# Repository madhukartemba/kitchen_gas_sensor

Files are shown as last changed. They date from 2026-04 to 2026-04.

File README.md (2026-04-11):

# kitchen_gas_sensor

This is a kitchen gas sensor using ESPHome. It detects gas leaks using an MQ-6 sensor and triggers an active buzzer alarm.

---

## 🔧 Hardware
- ESP32-C3
- MQ-6 Gas Sensor (analog output)
- Active buzzer
- 1x NeoPixel (status LED)
- Push button (reset)

---

## 🚀 Setup & Build

ESPHome version used: 2026.1.5
Python version used: 3.12.10

### ✅ Run
```bash
python -m esphome -s device_id 0 run gas_sensor.yaml
```

### ✅ Repair (Windows)
```bash
Remove-Item -Recurse -Force $env:USERPROFILE\.platformio -ErrorAction SilentlyContinue
Remove-Item -Recurse -Force .\.esphome -ErrorAction SilentlyContinue
```

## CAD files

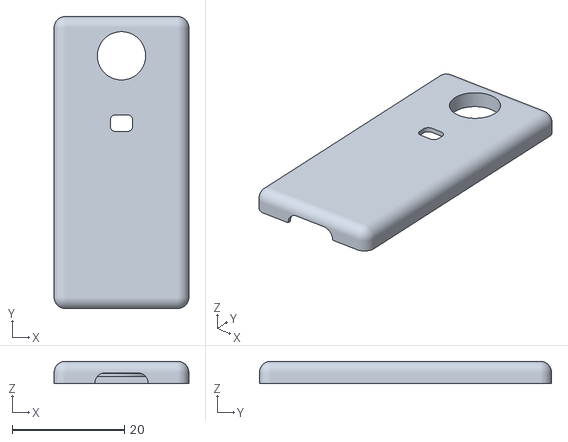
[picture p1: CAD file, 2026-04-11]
3D_Print/V2/Top.stl
24.0 x 52.0 x 4.00

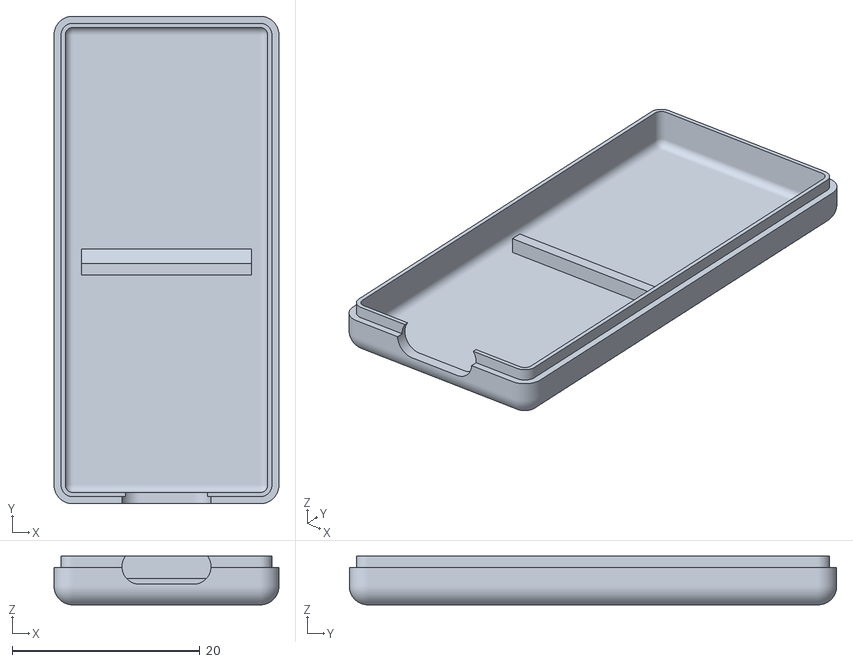
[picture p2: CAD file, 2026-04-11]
3D_Print/V2/Bottom.stl
24.0 x 52.0 x 5.20

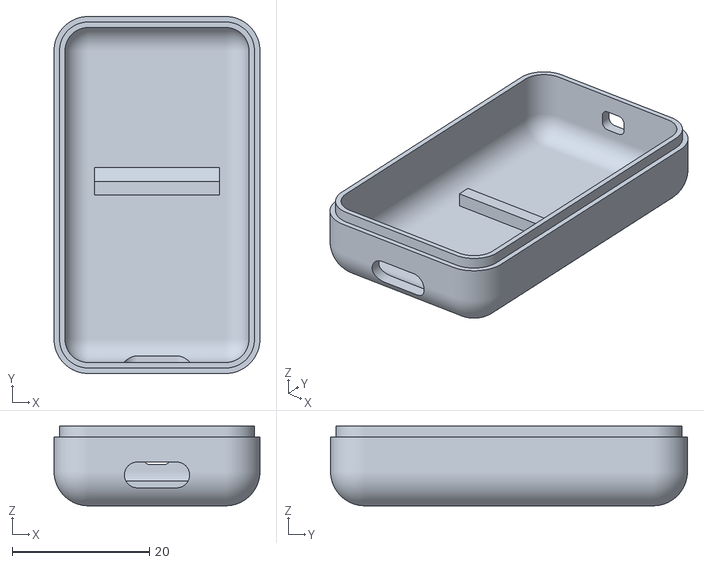
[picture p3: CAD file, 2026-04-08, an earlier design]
3D_Print/V1/Bottom.stl
30.0 x 52.0 x 11.6

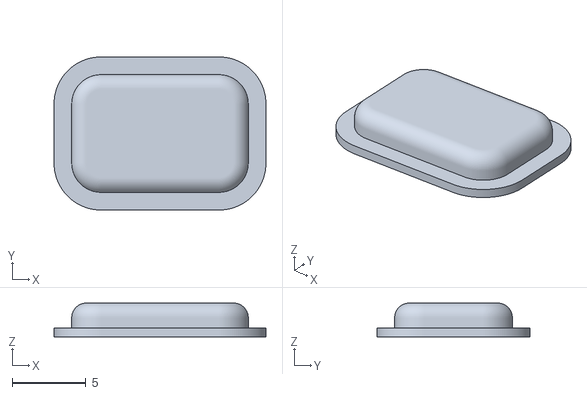
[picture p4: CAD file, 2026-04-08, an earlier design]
3D_Print/V1/LedCover.stl
14.4 x 10.4 x 2.30

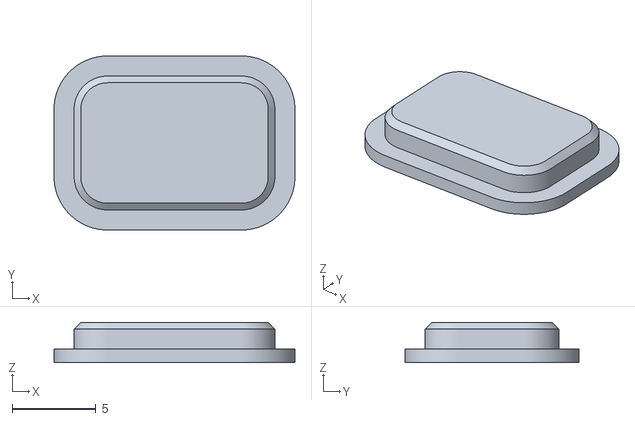
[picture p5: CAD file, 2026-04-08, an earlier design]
3D_Print/V1/Button.stl
14.4 x 10.4 x 2.40

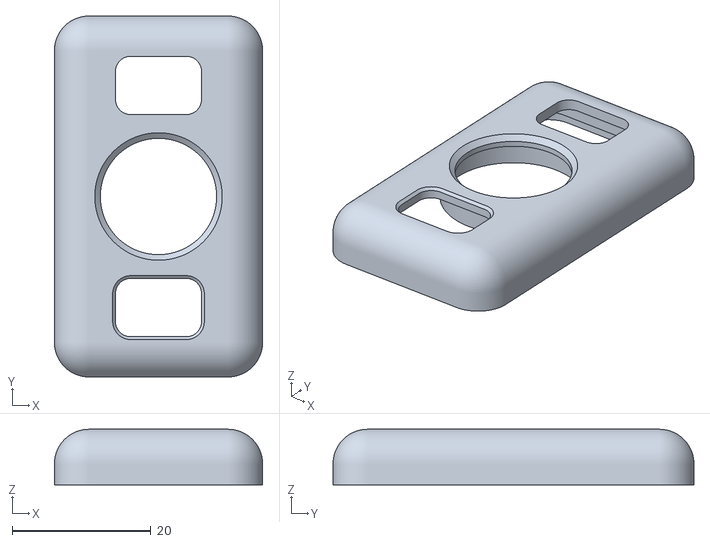
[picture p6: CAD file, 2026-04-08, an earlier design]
3D_Print/V1/Top.stl
30.0 x 52.0 x 8.00

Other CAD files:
3D_Print/V1/KitchenGasSensor.f3d
3D_Print/V2/GasSensorV2.f3d

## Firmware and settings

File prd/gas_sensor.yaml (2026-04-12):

substitutions:
  device_id: "0"

esphome:
  name: kitchen-gas-alarm-${device_id}
  friendly_name: Kitchen Gas Alarm ${device_id}
  # Include your custom C++ header
  includes:
    - SensorProcessor.h
  on_boot:
  # --- HARDWARE TEST ---
    - priority: 600
      then:
        - switch.turn_on: buzzer
        - light.turn_on:
            id: status_led
            red: 100%
            green: 100%
            blue: 100%
            brightness: 50%
            effect: "None"
        - delay: 1s
        - switch.turn_off: buzzer
        - light.turn_off: status_led
        - lambda: 'id(self_test_done) = true;'
    - priority: -10
      then:
        - lambda: |-
            get_processor()->setAbsoluteThreshold(id(gas_threshold).state);
            get_processor()->setRelativeThreshold(id(gas_rel_threshold).state);
            get_processor()->setNumberOfReadings(static_cast<int>(id(gas_reading_count).state));
            get_processor()->setWarmupTimeMs(static_cast<unsigned long>(id(gas_warmup_seconds).state * 1000.0f));
            get_processor()->setCooldownTimeMs(static_cast<unsigned long>(id(gas_cooldown_seconds).state * 1000.0f));
            get_processor()->setFaultVolts(id(gas_fault_trip_volts).state);
            get_processor()->setFaultClearVolts(id(gas_fault_clear_volts).state);

esp32:
  board: esp32-c3-devkitm-1
  framework:
    type: esp-idf

wifi:
  ssid: !secret wifi_ssid
  password: !secret wifi_password

logger:

api:

ota:
  - platform: esphome

# 🚩 Track if the startup test has finished
globals:
  - id: self_test_done
    type: bool
    initial_value: 'false'

# 1. Analog Gas Sensor - Exposed to HA
sensor:
  - platform: adc
    pin: GPIO0
    name: "Gas Level"
    id: gas_sensor
    # Read the physical pin very fast (5 times a second)
    update_interval: 200ms 
    attenuation: 12db
    filters:
      - sliding_window_moving_average:
          window_size: 5
          send_every: 5

# 3. Sensor State - Exposed to HA
text_sensor:
  - platform: template
    name: "Gas Sensor State"
    id: sensor_state
    update_interval: 1s
    lambda: |-
      switch (get_processor()->getState()) {
        case WARMUP: return std::string("Warmup");
        case NORMAL: return std::string("Normal");
        case ALARM: return std::string("Alarm");
        case COOLDOWN: return std::string("Cooldown");
        case ERROR: return std::string("Error");
      }
      return std::string("Unknown");

# Threshold slider (Home Assistant)
number:
  - platform: template
    name: "Gas Absolute Threshold"
    id: gas_threshold
    min_value: 0.0
    max_value: 3.3
    unit_of_measurement: "V"
    step: 0.01
    initial_value: 1.5
    restore_value: true
    optimistic: true
    on_value:
      then:
        - lambda: "get_processor()->setAbsoluteThreshold(x);"

  - platform: template
    name: "Gas Relative Threshold"
    id: gas_rel_threshold
    min_value: 0.0
    max_value: 3.3
    unit_of_measurement: "V"
    step: 0.01
    initial_value: 0.3
    restore_value: true
    optimistic: true
    on_value:
      then:
        - lambda: "get_processor()->setRelativeThreshold(x);"

  - platform: template
    name: "Gas reading count"
    id: gas_reading_count
    min_value: 1
    max_value: 3600
    step: 1
    initial_value: 300
    restore_value: true
    optimistic: true
    mode: box
    on_value:
      then:
        - lambda: "get_processor()->setNumberOfReadings(static_cast<int>(x));"

  - platform: template
    name: "Gas warmup duration"
    id: gas_warmup_seconds
    unit_of_measurement: "s"
    min_value: 0
    max_value: 600
    step: 1
    initial_value: 60
    restore_value: true
    optimistic: true
    mode: box
    on_value:
      then:
        - lambda: "get_processor()->setWarmupTimeMs(static_cast<unsigned long>(x * 1000.0f));"

  - platform: template
    name: "Gas cooldown duration"
    id: gas_cooldown_seconds
    unit_of_measurement: "s"
    min_value: 0
    max_value: 600
    step: 1
    initial_value: 30
    restore_value: true
    optimistic: true
    mode: box
    on_value:
      then:
        - lambda: "get_processor()->setCooldownTimeMs(static_cast<unsigned long>(x * 1000.0f));"

  - platform: template
    name: "Gas fault trip voltage"
    id: gas_fault_trip_volts
    unit_of_measurement: "V"
    min_value: 0.0
    max_value: 0.5
    step: 0.001
    initial_value: 0.02
    restore_value: true
    optimistic: true
    on_value:
      then:
        - lambda: "get_processor()->setFaultVolts(x);"

  - platform: template
    name: "Gas fault clear voltage"
    id: gas_fault_clear_volts
    unit_of_measurement: "V"
    min_value: 0.0
    max_value: 0.5
    step: 0.001
    initial_value: 0.05
    restore_value: true
    optimistic: true
    on_value:
      then:
        - lambda: "get_processor()->setFaultClearVolts(x);"

# 🔊 Buzzer (Internal only)
output:
  - platform: gpio
    pin: GPIO4
    id: buzzer_out
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

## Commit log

2026-04-08 add test code
    [Bottom.stl, Button.stl, LedCover.stl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]
2026-04-08 add export
    [KitchenGasSensor.f3d]
2026-04-11 move 3d print files
    [Bottom.stl, Button.stl, GasSensorV2.f3d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]
2026-04-11 add sensor processor file
2026-04-11 add led effects
2026-04-11 remove power save setting
2026-04-11 fix gamma led bug
    [gas_sensor.yaml]
2026-04-11 fix led brightness
